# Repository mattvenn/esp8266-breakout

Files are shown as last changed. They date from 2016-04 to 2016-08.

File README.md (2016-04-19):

# v3

* added pullup resistors for GPIO0 & CH_PD

# v2

* silkscreen of 4&5 changed
* silkscreen of ftdi pinout added

# v1

* bug: pins 4&5 switched - silkscreen of the modules lines up, but not working in SW
See adafruit's huzzah: https://learn.adafruit.com/adafruit-huzzah-esp8266-breakout/using-nodemcu-lua
* smt switch, which one from farnell?
* power led & resistor

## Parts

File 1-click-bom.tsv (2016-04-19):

Ref | Qty | Farnell
C1, C2, | 2 | 1190107
C3, | 1 | 1759297
C4, | 1 | 1759438
D1, | 1 | 2290335
P1, | 1
P2, | 1 | 1022263
R1, R4, R5, R6, | 4 | 2057856
R3, | 1 | 9336800
SW1, | 1 | 1867992
U1, | 1 | 1202826
esp8266, | 1

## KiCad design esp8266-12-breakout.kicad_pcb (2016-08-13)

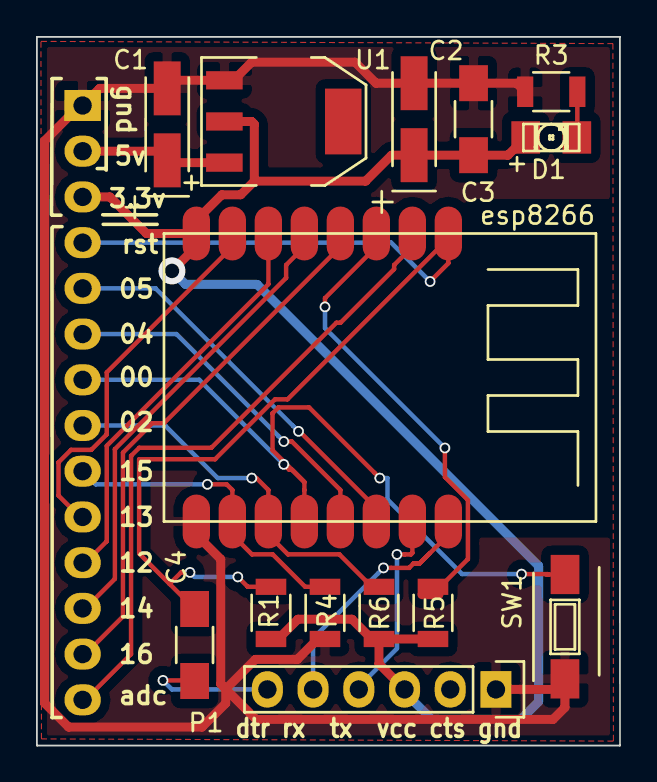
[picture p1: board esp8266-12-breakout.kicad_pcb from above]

Board: 2 copper layers, 32.4 x 39.4 mm, 15 parts (1 on the bottom side), 19 nets.

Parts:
C1, C2: 10uf; TantalC_SizeA_EIA-3216_HandSoldering
C3: 0.1uf; C_1206_HandSoldering
C4: 1uf; C_1206_HandSoldering
D1: LED; LED-1206
P1: ftdi; Pin_Header_Straight_1x06
P2: CONN_01X14; Pin_Header_Straight_1x14
R1, R4, R5, R6: 10k; R_1206
R3: 68r; R_1206
SW1: SW_PUSH; SW_SPST_FSMSM
U1: AP1117D33; SOT-223
esp8266: U2; esp8266-12

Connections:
+3V3: C2.1, C3.1, D1.2, P1.3, P2.3, R1.1, R4.1, R5.1, U1.2, esp8266.8
+5V: C1.1, P2.2, U1.3
/adc: P2.14, esp8266.2
/ch_pd: R5.2, esp8266.3
/gpio0: P2.7, SW1.1, esp8266.12
/gpio2: P2.8, R4.2, esp8266.11
/gpio4: P2.6, esp8266.13
/gpio5: P2.5, esp8266.14
/gpio12: P2.11, esp8266.6
/gpio13: P2.10, esp8266.7
/gpio14: P2.12, esp8266.5
/gpio15: P2.9, R6.1, esp8266.10
/gpio16: P2.13, esp8266.4
/reset: C4.2, P2.4, R1.2, esp8266.1
/rx: P1.4, esp8266.15
/tx: P1.5, esp8266.16
GND: C1.2, C2.2, C3.2, P1.1, P2.1, R3.2, R6.2, SW1.2, U1.1, esp8266.9
unnamed: C4.1, P1.6
unnamed: D1.1, R3.1

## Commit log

2015-07-25 sent to fab
    [esp8266-12-breakout.kicad_pcb, esp8266-12-breakout.sch]
2015-07-25 fixed gpio 4/5 mixup
    [esp8266-12-breakout.kicad_pcb, esp8266-12-breakout.sch]
2015-07-26 added reset pin to breakout for deepsleep
    [esp8266-12-breakout.kicad_pcb, esp8266-12-breakout.sch]
2015-08-17 added bom
2015-08-20 4&5 pin flip bug
2015-09-01 added header part #
    [esp8266-12-breakout.sch]
2015-09-01 serial silk screen and v2
    [esp8266-12-breakout.kicad_pcb]
2015-09-01 swapped gpio 4&5
    [esp8266-12-breakout.kicad_pcb, esp8266-12-breakout.sch]
2016-04-19 v3 added pull up resistors for gpio0 & 2
    [esp8266-12-breakout.kicad_pcb, esp8266-12-breakout.sch]
2016-04-19 readme & gerbers
    [esp8266-12-breakout-B_Cu.gbr, esp8266-12-breakout-B_Mask.gbr, esp8266-12-breakout-B_SilkS.gbr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]
2016-04-19 1click bom
    [1-click-BOM.tsv]
2016-04-19 removed old bom
2016-05-25 Update to new kitnic conventions
    [1-click-bom.tsv]
2016-08-13 Fix board outline and re-plot with newest KiCad
    [esp8266-12-breakout-B.Cu.gbr, esp8266-12-breakout-B.Mask.gbr, esp8266-12-breakout-B.SilkS.gbr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]
2016-08-13 Really strictly align outline
    [esp8266-12-breakout.kicad_pcb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]
